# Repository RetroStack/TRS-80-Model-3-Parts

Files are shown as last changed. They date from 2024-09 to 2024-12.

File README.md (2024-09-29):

# TRS-80 Model 3 - Parts

This project includes various items that were part of a TRS-80 Model 3 and have been replicated for 3D printing. Over time, things get lost or break, and this repository was created to provide a way to recover these lost items. The entire project is available under the MIT license.

Below is a list of available items, each with a link to a more detailed description and the STL file. If there is an item missing that you need, see the note at the end of this file.

## Keyboard

### Bezel

Keyboard Bezel

## External Links

N/A

## Missing Item?

Is an item you are looking for missing in this repo? Feel free to suggest this item to be digitized on my Patreon page (see below).

## Main TRS-80 Model 3 Repository

For additional resources related to the TRS-80 Model 3, be sure to check out the central page for the TRS-80 Model 3 on RetroStack. You can find it [here](https://www.github.com/RetroStack/TRS-80-Model-3).

## Support this Project

RetroStack is passionate about exploring and preserving the legacy of older computer systems. My work involves creating detailed documentation and videos to share the knowledge. I am also dedicated to reviving these classic systems by reimplementing them and offering replacement parts at no cost. If you're keen on supporting this unique project, I invite you to visit my [Patreon page](https://www.patreon.com/RetroStack). Your support would be immensely valuable and greatly appreciated!

## License

This project is licensed under the MIT License - see the [LICENSE](LICENSE) file for details.

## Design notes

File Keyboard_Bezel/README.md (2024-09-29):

# TRS-80 Model 3 - Keyboard Bezel

The keyboard bezel surrounds the keyswitches, covering the front of the case.

This repository has two types of bezels below:

## Original

This is a replicate of the original bezel.

- [STL Original](Model_3_Original.stl)

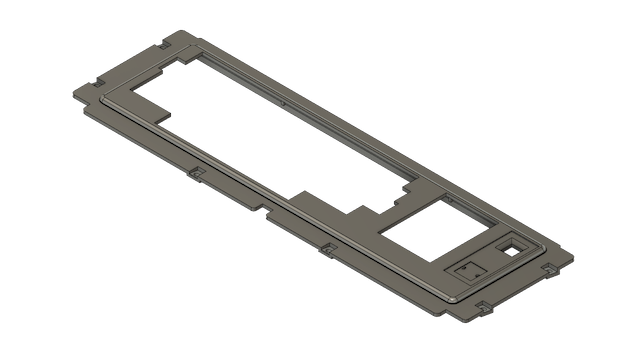
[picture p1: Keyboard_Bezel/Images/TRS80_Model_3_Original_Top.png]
Original Top

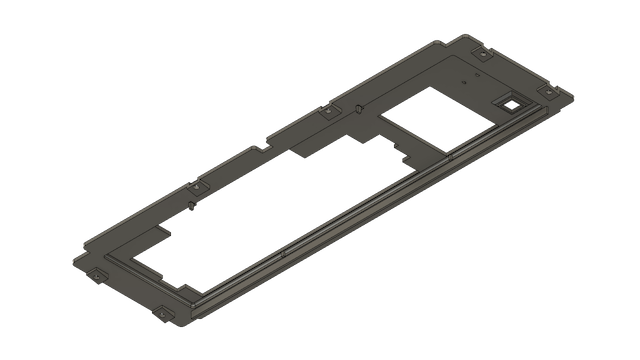
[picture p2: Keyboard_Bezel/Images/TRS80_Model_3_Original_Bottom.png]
Original Bottom


## Modern

This is a bezel that was made to fit [Jay Crutti's MX Replacement keyboard](https://www.jaycrutti.com/hardware-projects/tandy-trs-80-replacement-keyboards).

- [STL Modern](Model_3_Modern.stl)

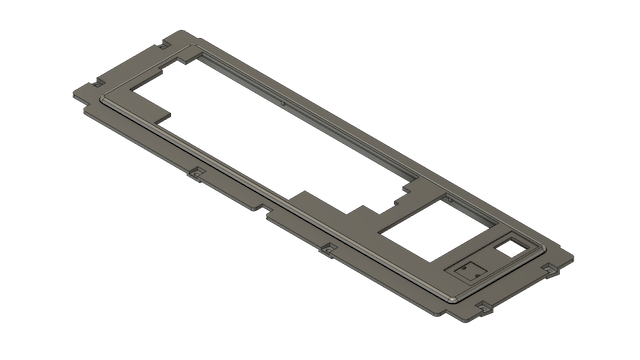
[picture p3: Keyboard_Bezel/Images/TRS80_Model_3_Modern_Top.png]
Modern Top

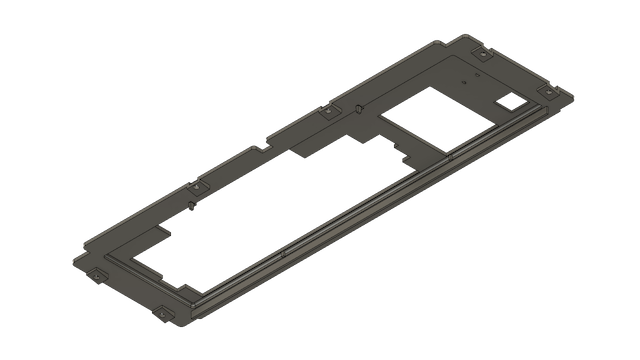
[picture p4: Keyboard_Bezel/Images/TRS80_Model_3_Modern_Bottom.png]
Modern Bottom


## Order Instruction - [JLC3DP](https://www.jlcpcb.com) (service of JLCPCB)

You can print them yourself, but most likely you do not have such a large printer. You can order them online. What follows are instructions for JLC3DP, which I've had good experiences with. Additionally, they take care of sanding and finishing.

- Go to [JLC3DP](https://www.jlcpcb.com).
- Click the "Quote Now" button under the "3D Printing" image.
- Click the "Add 3D file" and select the STL file provided above.

A few options appear. In either case, I always selected "SLA(Resin)" for the technology, which has a very smooth surface.

For the bezel, I would choose the "Black Resin" option. There are a few other black resin options which are all equaly good. It is a bit more expensive than the default, but it will reduce post-processing for you as you probably do not want a white bezel.

Leave all other options as-is.

You still have to select a "Product Description". Apparently, this is some customs requirement. I've selected for both "Office Appliances and Accessories" and "Keyboard Enclosure".

You can then hit "Save to Cart" and checkout.

By default, they will review your designs and send you an email to pay within a few hours. Simply go back to your order page (after you've created an account) and select "Pay".

NOTE: Most of the time, however, they will also send you an email to confirm that you want to assume the risk of ordering the design as-is as they are too long and may deform during production or have parts which are too thin. I've always accepted the risk.

NOTE: The design of this bezel is somewhat prone to bending. In most cases, it can be straightened by screwing it into the case and allowing the case frame to rest on top of it. Over a few days, it usually straightens out. However, there is always a risk that this may not work. Please be aware of this possibility.

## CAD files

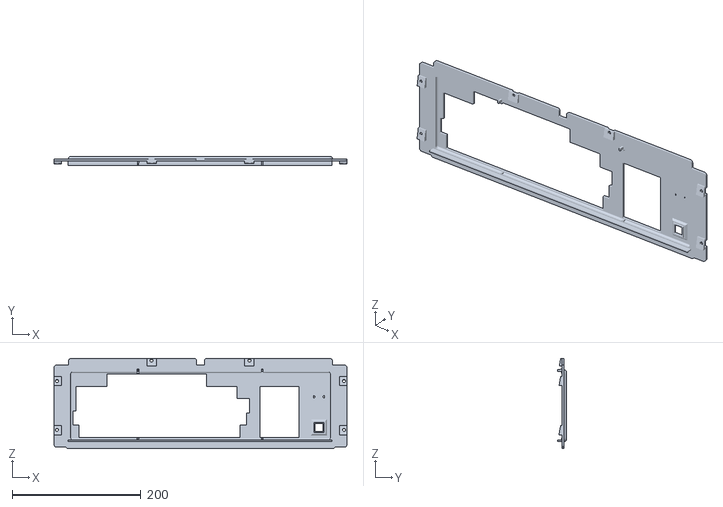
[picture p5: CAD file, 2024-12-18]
Keyboard_Bezel/Model_3_Original.stl
455.0 x 14.2 x 140.0

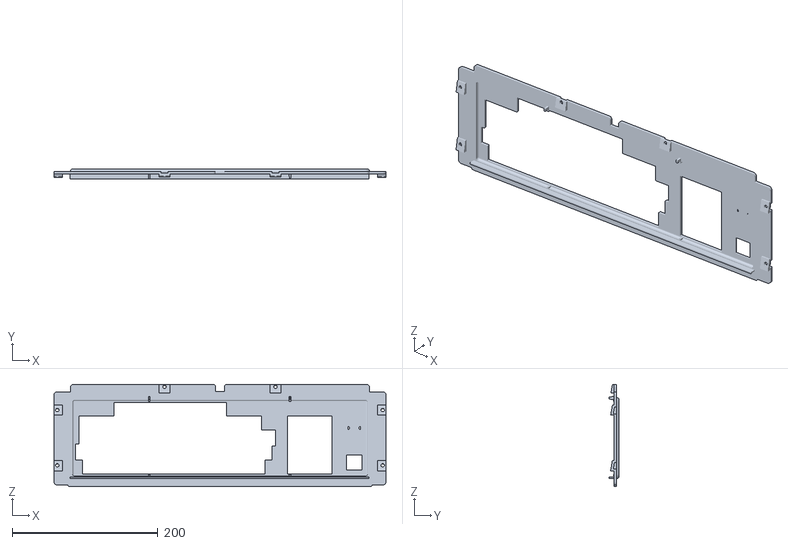
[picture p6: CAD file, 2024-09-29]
Keyboard_Bezel/Model_3_Modern.stl
455.0 x 14.2 x 140.0
